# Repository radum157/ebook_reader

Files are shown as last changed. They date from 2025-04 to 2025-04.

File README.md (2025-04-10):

###### Copyright Radu Marin 2025
## README
# OpenBook

# Table of content

1. [Hardware details](#hardware-details)
2. [Design](#design)
3. [Diagram](#diagram)
4. [Bill of Materials](#bill-of-materials)

# Hardware details

OpenBook is an e-reader platform based on ESP32-C6 with E-Paper display technology. This document outlines the hardware architecture, component selection, and design considerations.

### Primary components:

**ESP32-C6 Microcontroller**
- ESP32-C6-WROOM-1-N8 module

**E-Paper Display**
- Waveshare 7.5” e-Paper V2
- Connected via 24-pin FPC header
- MBR0530 diodes in drive circuit for voltage management
- Dedicated power regulation

### Power Management

**Battery System**
- CELLEVIA BATTERIES LP584174 3.7V / 1800mAh LiPo battery
- MCP73831 LiPo charging controller
- MAX17048G+T10 fuel gauge
- JST connector

**Voltage Regulation**
- XC6220A331MR-G LDO for stable 3.3V
- DMG2305UX-7 MOSFETs for reverse polarity protection
- BD5229G-TR supervisor for clean resets

### Storage & Memory

**SD Card**
- Full-size SD slot with presence detection
- SPI mode communication

**External Flash**
- W25Q512JVEIQ NOR Flash
- SPI interface with ESD protection

**RTC**
- DS3231SN precision timekeeper
- Super-cap backup power
- I2C interface shared with sensors

### Sensors & IO

**Environmental Sensing**
- BME688 for temperature, humidity, pressure, air quality
- I2C bus connection

**UI**
- Boot, Change and Reset buttons
- Test pads integrated as exposed copper

### Communication interfaces:

 * I2C:
    - Used for communication with the BME688 sensor and DS3231SN RTC.
    - Send/Receive data to/from the sensor and RTC.
    - Also used for MAX17048G+T10 fuel gauge monitoring
    - QWIIC connector for expansion

 * SPI:
    - Used for communication with the E-Paper display and SD Card.
    - The ESP32-C6 uses SPI to send data to the display and read/write to the SD card.
    - Also used for the external W25Q512JVEIQ flash memory

 * GPIO:
    - Used for the reset/boot button and other custom functionalities.

**USB-C**
- USB4110-GF-A connector
- USBLC6-2SC6Y for ESD protection on data lines
- Charging and data transfer

**SPI Configuration**
- 10MHz clock rate
- Individual chip selects
- Shared data and clock lines

**I2C Setup**
- 400kHz standard mode
- 4.7kΩ pull-ups
- Shared among BME688, MAX17048G+T10, DS3231SN, and QWIIC port

**USB Interface**
- 5V, 500mA input

### Pins used:

| Pin | Function | Connected To | Why |
|-----|---|---|---|
| GPIO0 | BOOT | Boot/Reset Button | Flash mode access |
| GPIO1/2 | UART | USB-Serial | Debugging |
| GPIO3-4, 6-7 | SD Card | SD interface | Dedicated SD pins for reliability |
| GPIO5 | EPD_CS | E-Paper CS line | Display control |
| GPIO8 | FLASH_CS | External Flash | Flash memory selection |
| GPIO9-11 | SPI Bus | Shared SPI | Central bus for all SPI devices |
| GPIO12-13 | I2C Bus | Sensors & expansion | Shared I2C for all sensors |
| GPIO14-16 | EPD Control | E-Paper control signals | Timing control |
| GPIO17 | ADC | Battery voltage | Power monitoring |
| GPIO19-23 | EPD Data | E-Paper data lines | Display data transfer |

### Power consumption:
- Display refresh: ~125mA @ 3.3V
- Idle: ~25mA @ 3.3V
- Deep sleep: ~150μA @ 3.3V
- Duty cycle: 1-2 weeks typical use (1800mAh battery)

# Design

The final design of the PCB and 3D model attempt to minimize noise interference and maximize ease-of-use, while maintaining all of the core functionalities of OpenBook.

**Metoda de rezolvare / Probleme intampinate**

Schematic:

- Implemented following the electric design of the e-book reader
- Approved errors in relation to power pins

PCB 2D:

- Measured the dimensions and distances on the board and added the components accordingly (only on top layer)
- Approved errors in relation to board outline clearance (components in question needed to be closer to the enclosure)
- Added net classes to separate power lines from regular ones
- Created the power lines on top, with no vias, then the rest, all while attempting to optimize routing
- Added GND on top and bottom with no holes
- Via stitching close to ESP32

PCB 3D:

- Ensured soldermask layer is visible and at a small distance from the circuitry on the board
- Added accurate models for all components in use

Final 3D design:

- Added the pcb to the enclosure
- Modified the box shape for the SD, buttons etc. to fit
- Created a model for the Li-Po battery and 7.5” display
- Put everything together to ensure it fits

<br>

**The end result**

<br>

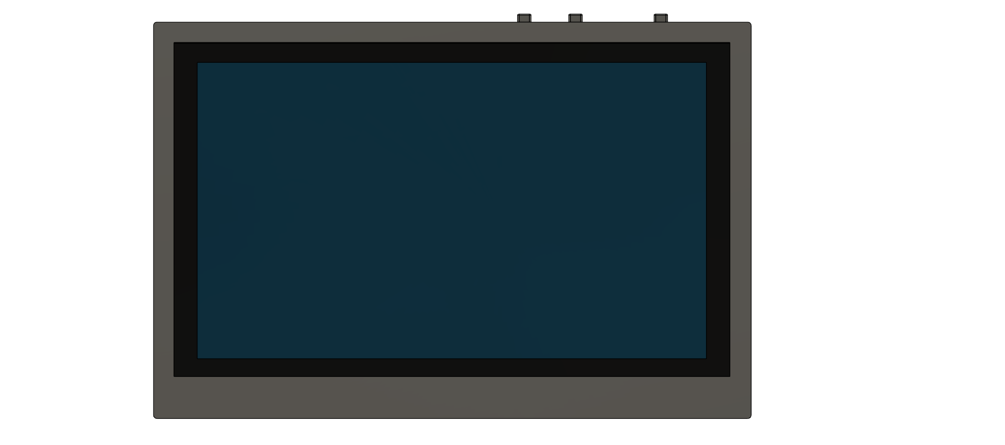
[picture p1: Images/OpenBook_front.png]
case1


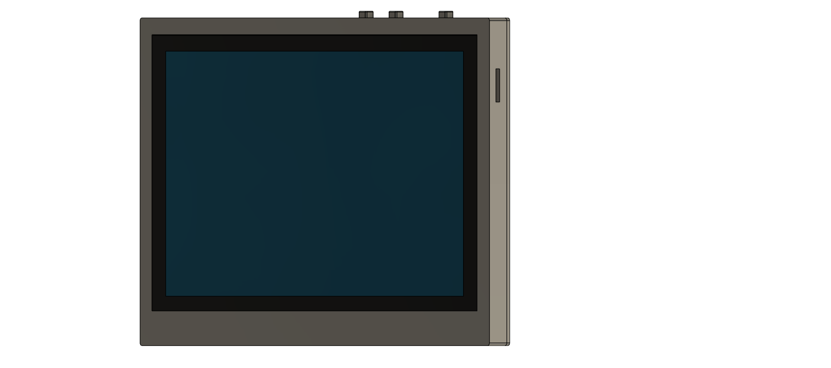
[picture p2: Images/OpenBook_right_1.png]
case2


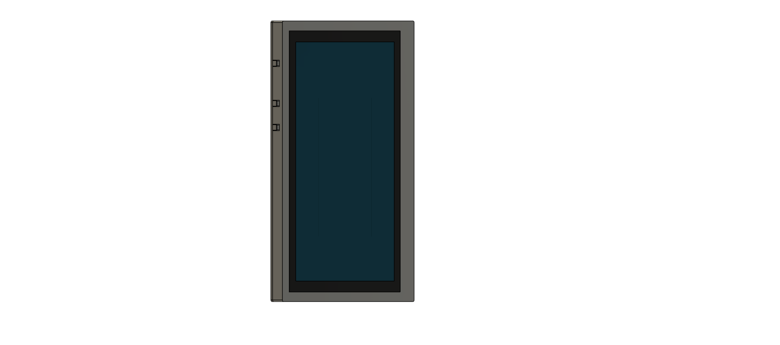
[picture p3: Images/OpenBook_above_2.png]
case3


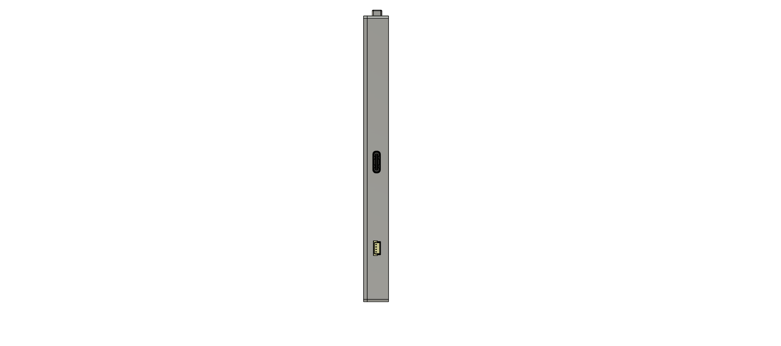
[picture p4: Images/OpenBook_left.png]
case4


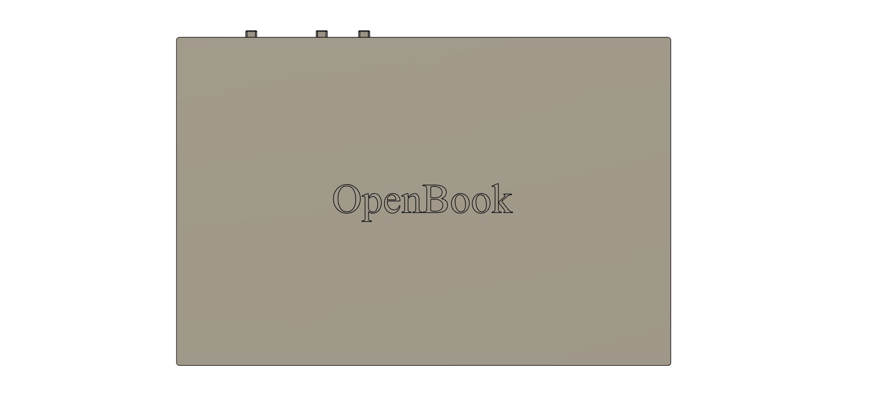
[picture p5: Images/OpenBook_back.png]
case5


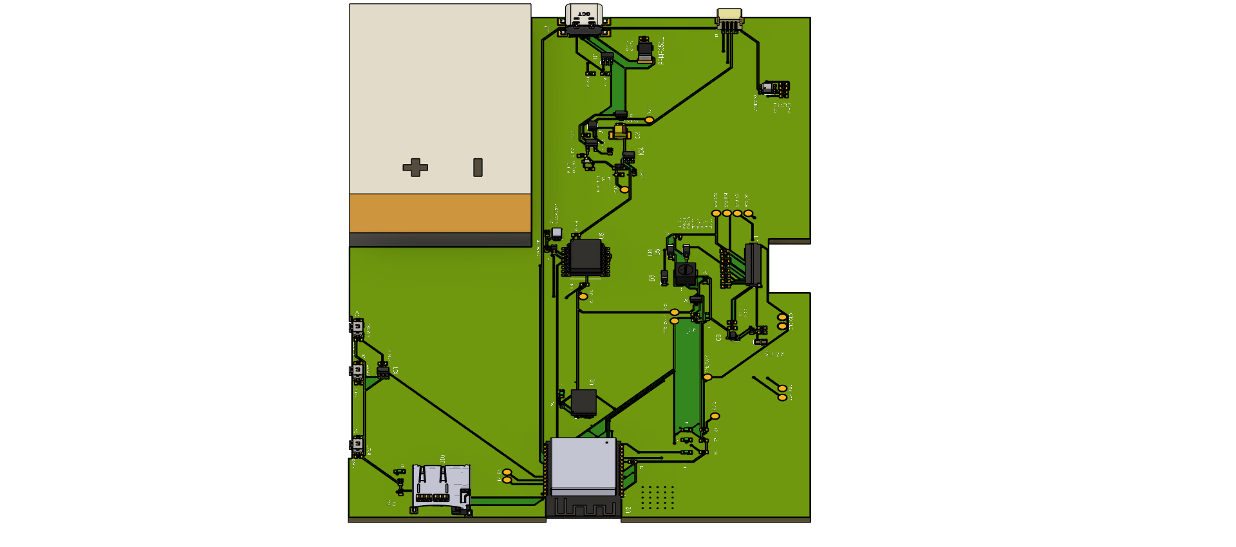
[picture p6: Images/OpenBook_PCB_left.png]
pcb1


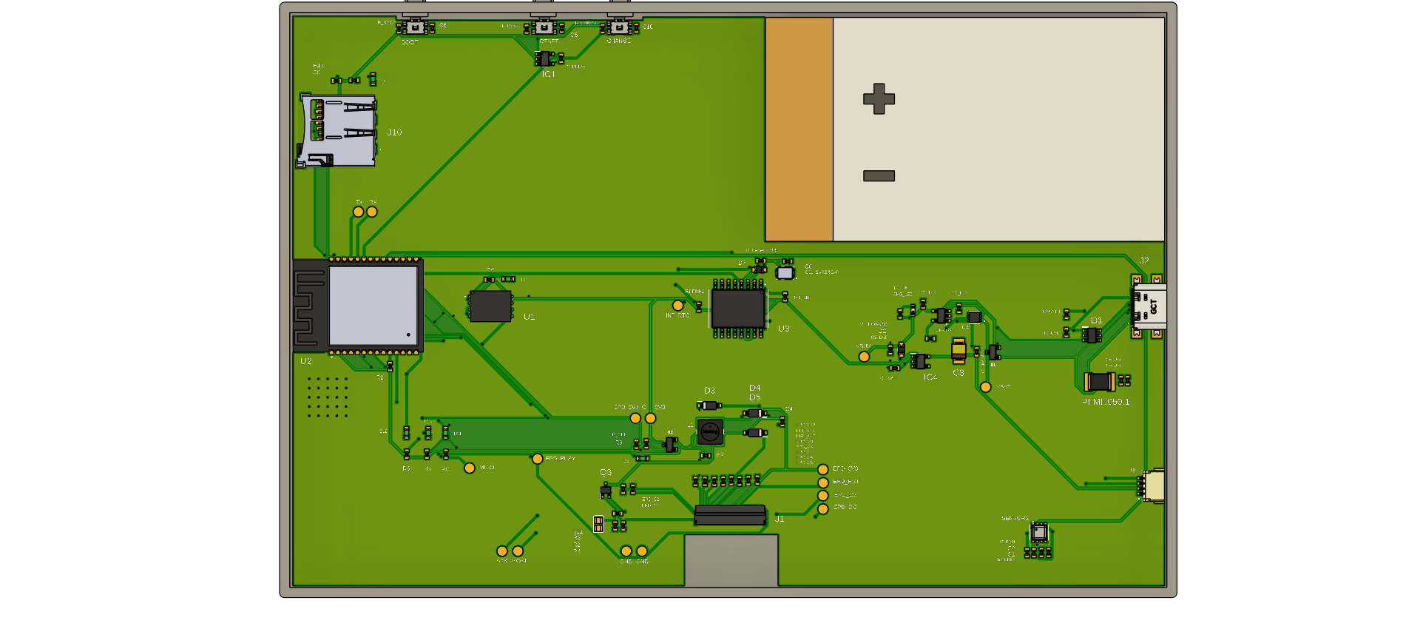
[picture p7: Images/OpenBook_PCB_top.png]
pcb2


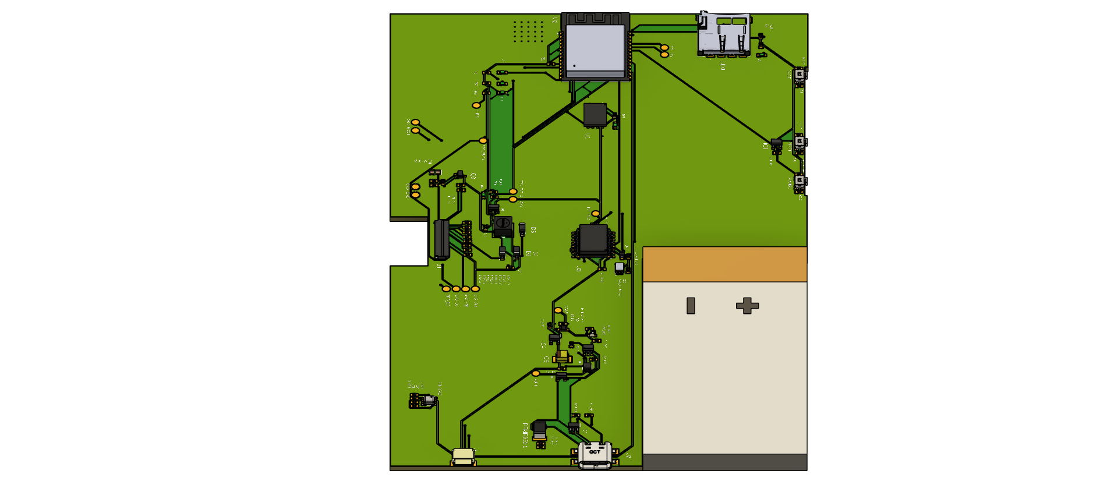
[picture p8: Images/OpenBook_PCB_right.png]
pcb3


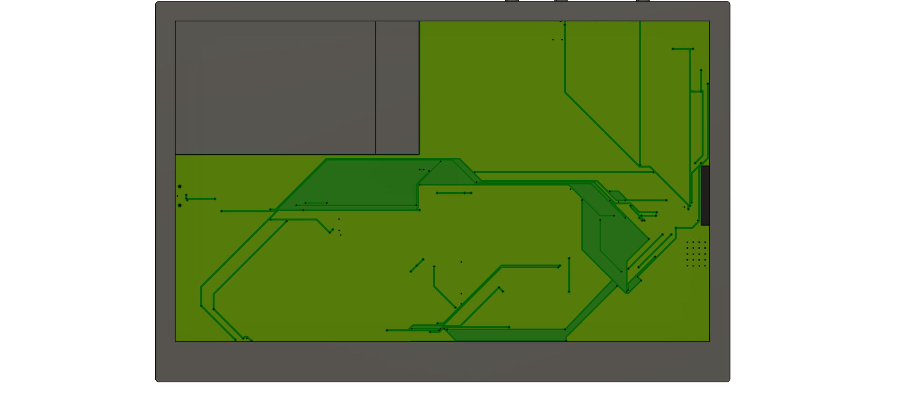
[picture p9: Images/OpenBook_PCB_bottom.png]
pcb4


# Diagram

diagram

# Bill of Materials

| Qty | Value | Device | Parts | CHECK_PRICES | DATASHEET |
|:---:|:---|:---|:---|:---|:---|
| 1 | 0.47 | ESP32_WROVER_EAGLE-LTSPICE_RR0402 | R3 | [YAGEO](https://componentsearchengine.com/part-view/R0402%201%25%20100%20K%20(RC0402FR-07100KL)/YAGEO) | [Datasheet](https://www.yageo.com/upload/media/product/products/datasheet/rchip/PYu-RC_Group_51_RoHS_L_12.pdf) |
| 1 | 100k | ESP32_WROVER_EAGLE-LTSPICE_RR0402 | R1_PWRUSB | [YAGEO](https://componentsearchengine.com/part-view/R0402%201%25%20100%20K%20(RC0402FR-07100KL)/YAGEO) | [Datasheet](https://www.yageo.com/upload/media/product/products/datasheet/rchip/PYu-RC_Group_51_RoHS_L_12.pdf) |
| 8 | 100nF | EAGLE-LTSPICE_CC0402 | C1, C2, C4_USB, C6, C8, C9, C10, C_DELAY | [YAGEO](https://componentsearchengine.com/part-view/CC0402MRX5R5BB106/YAGEO) | [Datasheet](https://ro.mouser.com/datasheet/2/447/upy_gphc_x5r_4v_to_50v-3461255.pdf) |
| 1 | 100uF TANT | RCL_CPOL-EUCT3528 | C3 | [Mouser](https://eu.mouser.com/ProductDetail/KYOCERA-AVX/TPSB106K025T1800?qs=qSfuJ%252Bfl%2Fd753zkuSz4nrg%3D%3D) | [Datasheet](https://eu.mouser.com/datasheet/2/40/TPS_AUTO-3165215.pdf) |
| 16 | 10k | ESP32_WROVER_EAGLE-LTSPICE_RR0402 | R1, R1-PINH, R1-PINH1, R2-PINH, R2-PINH1, R4, R5, R6, R7, R8, R9, R10, R_BOOT, R_CHANGE, R_CL1, R_RESET | [YAGEO](https://componentsearchengine.com/part-view/R0402%201%25%20100%20K%20(RC0402FR-07100KL)/YAGEO) | [Datasheet](https://www.yageo.com/upload/media/product/products/datasheet/rchip/PYu-RC_Group_51_RoHS_L_12.pdf) |
| 1 | 10uF | EAGLE-LTSPICE_CC0402 | C7 | [YAGEO](https://componentsearchengine.com/part-view/CC0402MRX5R5BB106/YAGEO) | [Datasheet](https://ro.mouser.com/datasheet/2/447/upy_gphc_x5r_4v_to_50v-3461255.pdf) |
| 1 | 112A-TAAR-R03_ATTEND | 112A-TAAR-R03_ATTEND | J10 | [Comet](https://store.comet.srl.ro/Catalogue/Product/43497/) | [Datasheet](https://www.attend.com.tw/en/product.php?act=view&id=253) |
| 1 | 15 | ESP32_WROVER_EAGLE-LTSPICE_RR0402 | R_CAPACITOR | [YAGEO](https://componentsearchengine.com/part-view/R0402%201%25%20100%20K%20(RC0402FR-07100KL)/YAGEO) | [Datasheet](https://www.yageo.com/upload/media/product/products/datasheet/rchip/PYu-RC_Group_51_RoHS_L_12.pdf) |
| 1 | 1m | SJ | SJ1 | - | - |
| 1 | 1uF | EAGLE-LTSPICE_CC0402 | C5 | [YAGEO](https://componentsearchengine.com/part-view/CC0402MRX5R5BB106/YAGEO) | [Datasheet](https://ro.mouser.com/datasheet/2/447/upy_gphc_x5r_4v_to_50v-3461255.pdf) |
| 10 | 1uF/50V | EAGLE-LTSPICE_CC0402 | EPD_C1, EPD_C2, EPD_C5, EPD_C6, EPD_C7, EPD_C8, EPD_C9, EPD_C10, EPD_C11, EPD_C12 | [YAGEO](https://componentsearchengine.com/part-view/CC0402MRX5R5BB106/YAGEO) | [Datasheet](https://ro.mouser.com/datasheet/2/447/upy_gphc_x5r_4v_to_50v-3461255.pdf) |
| 1 | 2.2 | ESP32_WROVER_EAGLE-LTSPICE_RR0402 | R2 | [YAGEO](https://componentsearchengine.com/part-view/R0402%201%25%20100%20K%20(RC0402FR-07100KL)/YAGEO) | [Datasheet](https://www.yageo.com/upload/media/product/products/datasheet/rchip/PYu-RC_Group_51_RoHS_L_12.pdf) |
| 1 | 200 | ESP32_WROVER_EAGLE-LTSPICE_RR0402 | R1_BAT | [YAGEO](https://componentsearchengine.com/part-view/R0402%201%25%20100%20K%20(RC0402FR-07100KL)/YAGEO) | [Datasheet](https://www.yageo.com/upload/media/product/products/datasheet/rchip/PYu-RC_Group_51_RoHS_L_12.pdf) |
| 2 | 20V/4.2A/52mO/1.4W | ESP32_WROVER_SPARKFUN-DISCRETESEMI_MOSFET_PCH-DMG2305UX-7 | Q1, Q2 | [Diodes Inc](https://componentsearchengine.com/part-view/DMG2305UX-7/Diodes%20Incorporated) | [Datasheet](https://www.diodes.com/assets/Datasheets/DMG2305UX.pdf) |
| 1 | 2k | ESP32_WROVER_EAGLE-LTSPICE_RR0402 | R2_BAT | [YAGEO](https://componentsearchengine.com/part-view/R0402%201%25%20100%20K%20(RC0402FR-07100KL)/YAGEO) | [Datasheet](https://www.yageo.com/upload/media/product/products/datasheet/rchip/PYu-RC_Group_51_RoHS_L_12.pdf) |
| 5 | 4.7uF | EAGLE-LTSPICE_CC0402 | C1_BAT, C1_BAT1, C1_BAT2, C2_BAT, C5_USB | [YAGEO](https://componentsearchengine.com/part-view/CC0402MRX5R5BB106/YAGEO) | [Datasheet](https://ro.mouser.com/datasheet/2/447/upy_gphc_x5r_4v_to_50v-3461255.pdf) |
| 1 | 4.7uF/25V | EAGLE-LTSPICE_CC0402 | C4 | [YAGEO](https://componentsearchengine.com/part-view/CC0402MRX5R5BB106/YAGEO) | [Datasheet](https://ro.mouser.com/datasheet/2/447/upy_gphc_x5r_4v_to_50v-3461255.pdf) |
| 2 | 5k1 | ESP32_WROVER_EAGLE-LTSPICE_RR0402 | R2-USB, R2-USB1 | [YAGEO](https://componentsearchengine.com/part-view/R0402%201%25%20100%20K%20(RC0402FR-07100KL)/YAGEO) | [Datasheet](https://www.yageo.com/upload/media/product/products/datasheet/rchip/PYu-RC_Group_51_RoHS_L_12.pdf) |
| 1 | 68uH | 744043680IND_4828-WE-TPC_WRE | L1 | [Mouser](https://eu.mouser.com/ProductDetail/Wurth-Elektronik/744043680?qs=PGXP4M47uW6VkZq%252BkzjrHA%3D%3D) | [Datasheet](https://www.we-online.com/components/products/datasheet/744043680.pdf) |
| 1 | BD5229G-TR | BD5229G-TR | IC1 | [ROHM](https://componentsearchengine.com/part-view/BD5229G-TR/ROHM%20Semiconductor) | [Datasheet](https://fscdn.rohm.com/en/products/databook/datasheet/ic/power/voltage_detector/bd52xxg-e.pdf) |
| 1 | BME688 | ESP32_WROVER_BME680_BME680 | SENSOR2 | [SnapEDA](https://www.snapeda.com/parts/BME680/Bosch/view-part/?welcome=home) | [Datasheet](https://www.snapeda.com/parts/BME680/Bosch%20Sensortec/datasheet/) |
| 3 | BUTTON_CUSYOMV1 | BUTTON_CUSYOMV1 | BOOT_BUTTON, CHANGE_BUTTON, RESET_BUTTON | [Panasonic](https://industry.panasonic.com/global/en/products/control/switch/light-touch/number/evqpuj02k) | [Datasheet](https://www.alldatasheet.com/datasheet-pdf/pdf/537835/PANASONIC/EVQPUJ02K.html) |
| 1 | CPH3225A | CPH3225A | C10_SUPERCAP | [SnapEDA](https://www.snapeda.com/parts/CPH3225A/Seiko+Instruments/view-part/?ref=eda) | [Datasheet](https://www.snapeda.com/parts/CPH3225A/Seiko%20Instruments/datasheet/) |
| 1 | DS3231SN# | DS3231SN# | U3 | [SnapEDA](https://www.snapeda.com/parts/DS3231SN%23/Analog+Devices/view-part/?ref=eda) | [Datasheet](https://www.snapeda.com/parts/DS3231SN%23/Analog%20Devices/datasheet/) |
| 1 | ESP32-C6-WROOM-1-N8 | ESP32-C6-WROOM-1-N8 | U2 | [SnapEDA](https://www.snapeda.com/parts/ESP32-C6-WROOM-1-N8/Espressif+Systems/view-part/?ref=eda) | [Datasheet](https://www.snapeda.com/parts/ESP32-C6-WROOM-1-N8/Espressif%20Systems/datasheet/) |
| 1 | ESP32C6_VARISTORCN1812 | ESP32C6_VARISTORCN1812 | PFMF.050.1 | [Digikey](https://www.digikey.com/en/products/detail/abracon-llc/AMCV-1812H-180-T/4245629) | [Datasheet](https://abracon.com/Magnetics/circuit_protection/AMCV-1812H.pdf) |
| 2 | ESP32_WROVER_AVX-SD0805S020S1R0 | ESP32_WROVER_AVX-SD0805S020S1R0 | D2, D7 | [Mouser](https://eu.mouser.com/ProductDetail/KYOCERA-AVX/SD0805S020S1R0?qs=jCA%252BPfw4LHbpkAoSnwrdjw%3D%3D) | [Datasheet](http://datasheets.avx.com/schottky.pdf) |
| 1 | ESP32_WROVER_SPARKFUN-IC-POWER_MCP73831 | ESP32_WROVER_SPARKFUN-IC-POWER_MCP73831 | MCP73831 | [Mouser](https://www.mouser.co.uk/ProductDetail/Microchip-Technology/MCP73831T-5ACI-OT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) | [Datasheet](https://www.mouser.co.uk/datasheet/2/268/MCP73831_Family_Data_Sheet_DS20001984H-3441711.pdf) |
| 1 | FH34SRJ-24S-0.5SH_99_ | FH34SRJ-24S-0.5SH_99_ | J1 | [Hirose](https://componentsearchengine.com/part-view/FH34SRJ-24S-0.5SH(99)/Hirose) | [Datasheet](https://www.hirose.com/en/product/document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) |
| 1 | MAX17048G+T10 | MAX17048G+T10 | U4 | [SnapEDA](https://www.snapeda.com/parts/MAX17048G+T10/Analog+Devices/view-part/?ref=eda) | [Datasheet](https://www.snapeda.com/parts/MAX17048G+T10/Analog%20Devices/datasheet/) |
| 3 | MBR0530 | MBR0530 | D3, D4, D5 | [SnapEDA](https://www.snapeda.com/parts/MBR0530/Onsemi/view-part/?ref=eda) | [Datasheet](https://www.snapeda.com/parts/MBR0530/ON%20Semiconductor/datasheet/) |
| 6 | PGB1010603MR | PGB1010603MR | D6, D8, D9, D10, D11, D12 | [SnapEDA](https://www.snapeda.com/parts/PGB1010603MR/Littelfuse/view-part/?ref=eda) | [Datasheet](https://www.snapeda.com/parts/PGB1010603MR/Littelfuse%20Inc./datasheet/) |
| 1 | QWIIC_RIGHT_ANGLE | QWIIC_CONNECTORJS-1MM | J3 | [SnapEDA](https://www.snapeda.com/parts/PRT-14417/SparkFun%20Electronics/view-part/?ref=search&t=qwiic) | [Datasheet](https://www.snapeda.com/parts/PRT-14417/SparkFun%20Electronics/datasheet/) |
| 1 | SAMACSYS_PARTS_USB4110-GF-A | SAMACSYS_PARTS_USB4110-GF-A | J2 | [GCT](https://componentsearchengine.com/part-view/USB4110-GF-A/GCT%20(GLOBAL%20CONNECTOR%20TECHNOLOGY)) | [Datasheet](https://ro.mouser.com/datasheet/2/837/GCT_USB4110_Product_Drawing___20k_cycles-3455479.pdf) |
| 1 | SI1308EDL-T1-GE3 | SI1308EDL-T1-GE3 | Q3 | [SnapEDA](https://www.snapeda.com/parts/SI1308EDL-T1-GE3/Vishay+Siliconix/view-part/?ref=eda) | [Datasheet](https://www.snapeda.com/parts/SI1308EDL-T1-GE3/Vishay%20Siliconix/datasheet/) |
| 1 | SMD-LED0603 | ADAFRUIT_LEDCHIP-LED0603 | CHG_LED | [SnapEDA](https://www.snapeda.com/parts/KP-1608SURCK/Kingbright/view-part/?ref=search&t=LED%200603) | [Datasheet](https://www.snapeda.com/parts/KP-1608SURCK/Kingbright/datasheet/) |
| 17 | TPTP20R | TPTP20R | TP1, TP2, TP3, TP4, TP5, TP6, TP7, TP8, TP9, TP10, TP11, TP12, TP13, TP14, TP15, TP16, TP17 | - | - |
| 1 | USBLC6-2SC6Y | USBLC6-2SC6Y | D1 | [SnapEDA](https://www.snapeda.com/parts/USBLC6-2SC6Y/STMicroelectronics/view-part/?ref=eda) | [Datasheet](https://www.snapeda.com/parts/USBLC6-2SC6Y/STMicroelectronics/datasheet/) |
| 1 | W25Q512JVEIQ | W25Q512JVEIQ | U1 | [SnapEDA](https://www.snapeda.com/parts/W25Q512JVEIQ/Winbond+Electronics/view-part/?ref=eda) | [Datasheet](https://www.snapeda.com/parts/W25Q512JVEIQ/Winbond%20Electronics/datasheet/) |
| 1 | XC6220A331MR-G | XC6220A331MR-G | IC4 | [Torex](https://componentsearchengine.com/part-view/XC6220A331MR-G/Torex) | [Datasheet](https://eu.mouser.com/datasheet/2/760/xc6220-3371556.pdf) |

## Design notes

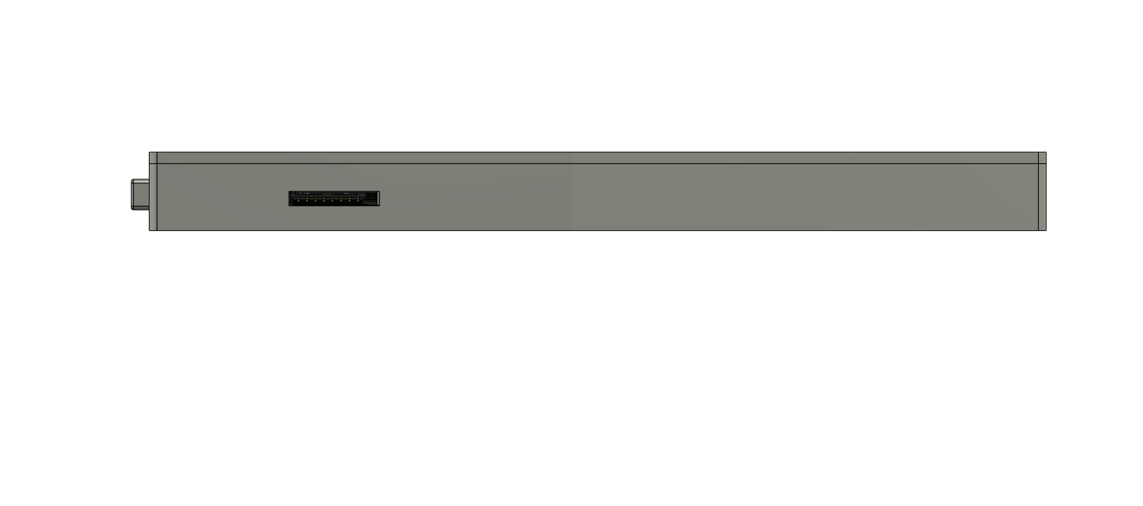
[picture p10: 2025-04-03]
Images/OpenBook_right_2.png

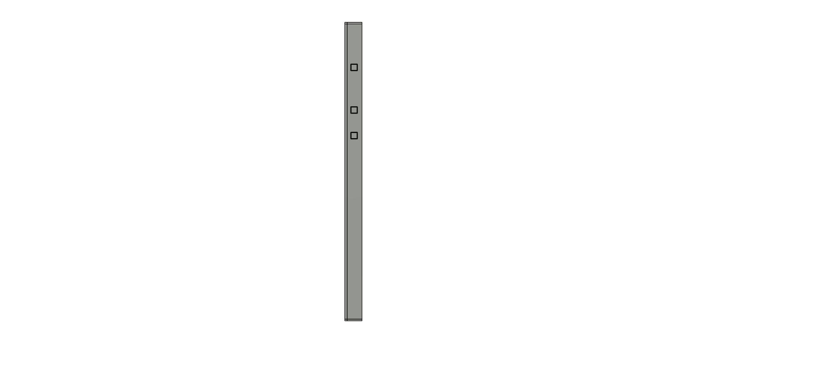
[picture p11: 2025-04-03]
Images/OpenBook_above_1.png

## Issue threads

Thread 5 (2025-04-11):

Gaps in ground plane

patriciacraciun, 2025-04-11:
The ground plane has unnecessary gaps, it should be continuous.

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

radum157, 2025-04-11:
This seems to be an issue with how fusion saves the board. This is how it actually looks for referrence.

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

Closed 2025-04-11.

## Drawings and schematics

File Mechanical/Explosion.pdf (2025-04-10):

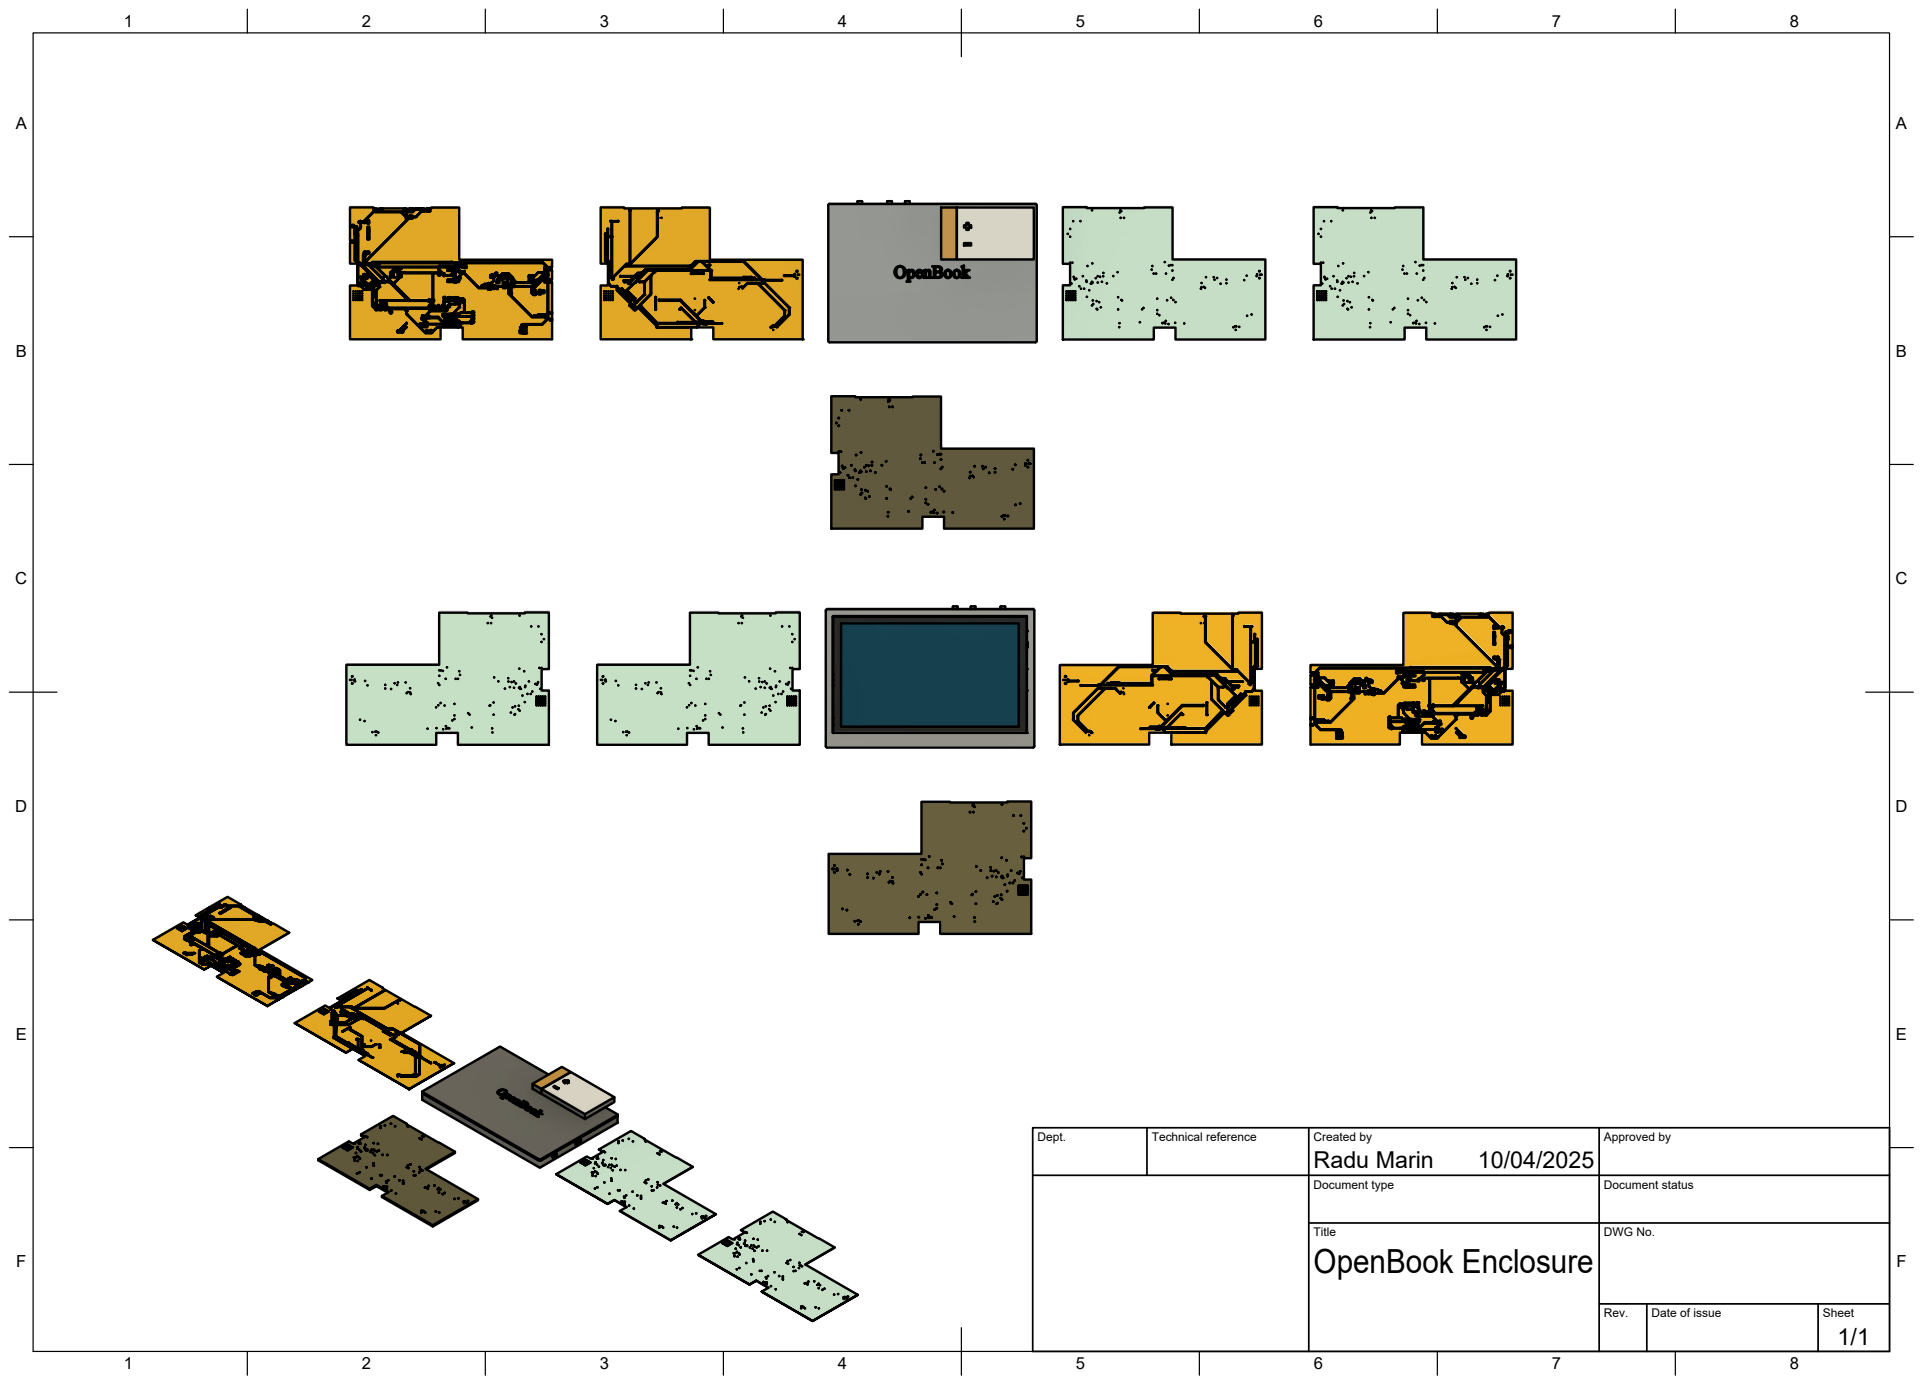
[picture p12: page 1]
Dept.; Technical reference; Created by; Approved by; Document type; Document status; Title; DWG No.; Rev.; Date of issue; Sheet; OpenBook Enclosure; Radu Marin

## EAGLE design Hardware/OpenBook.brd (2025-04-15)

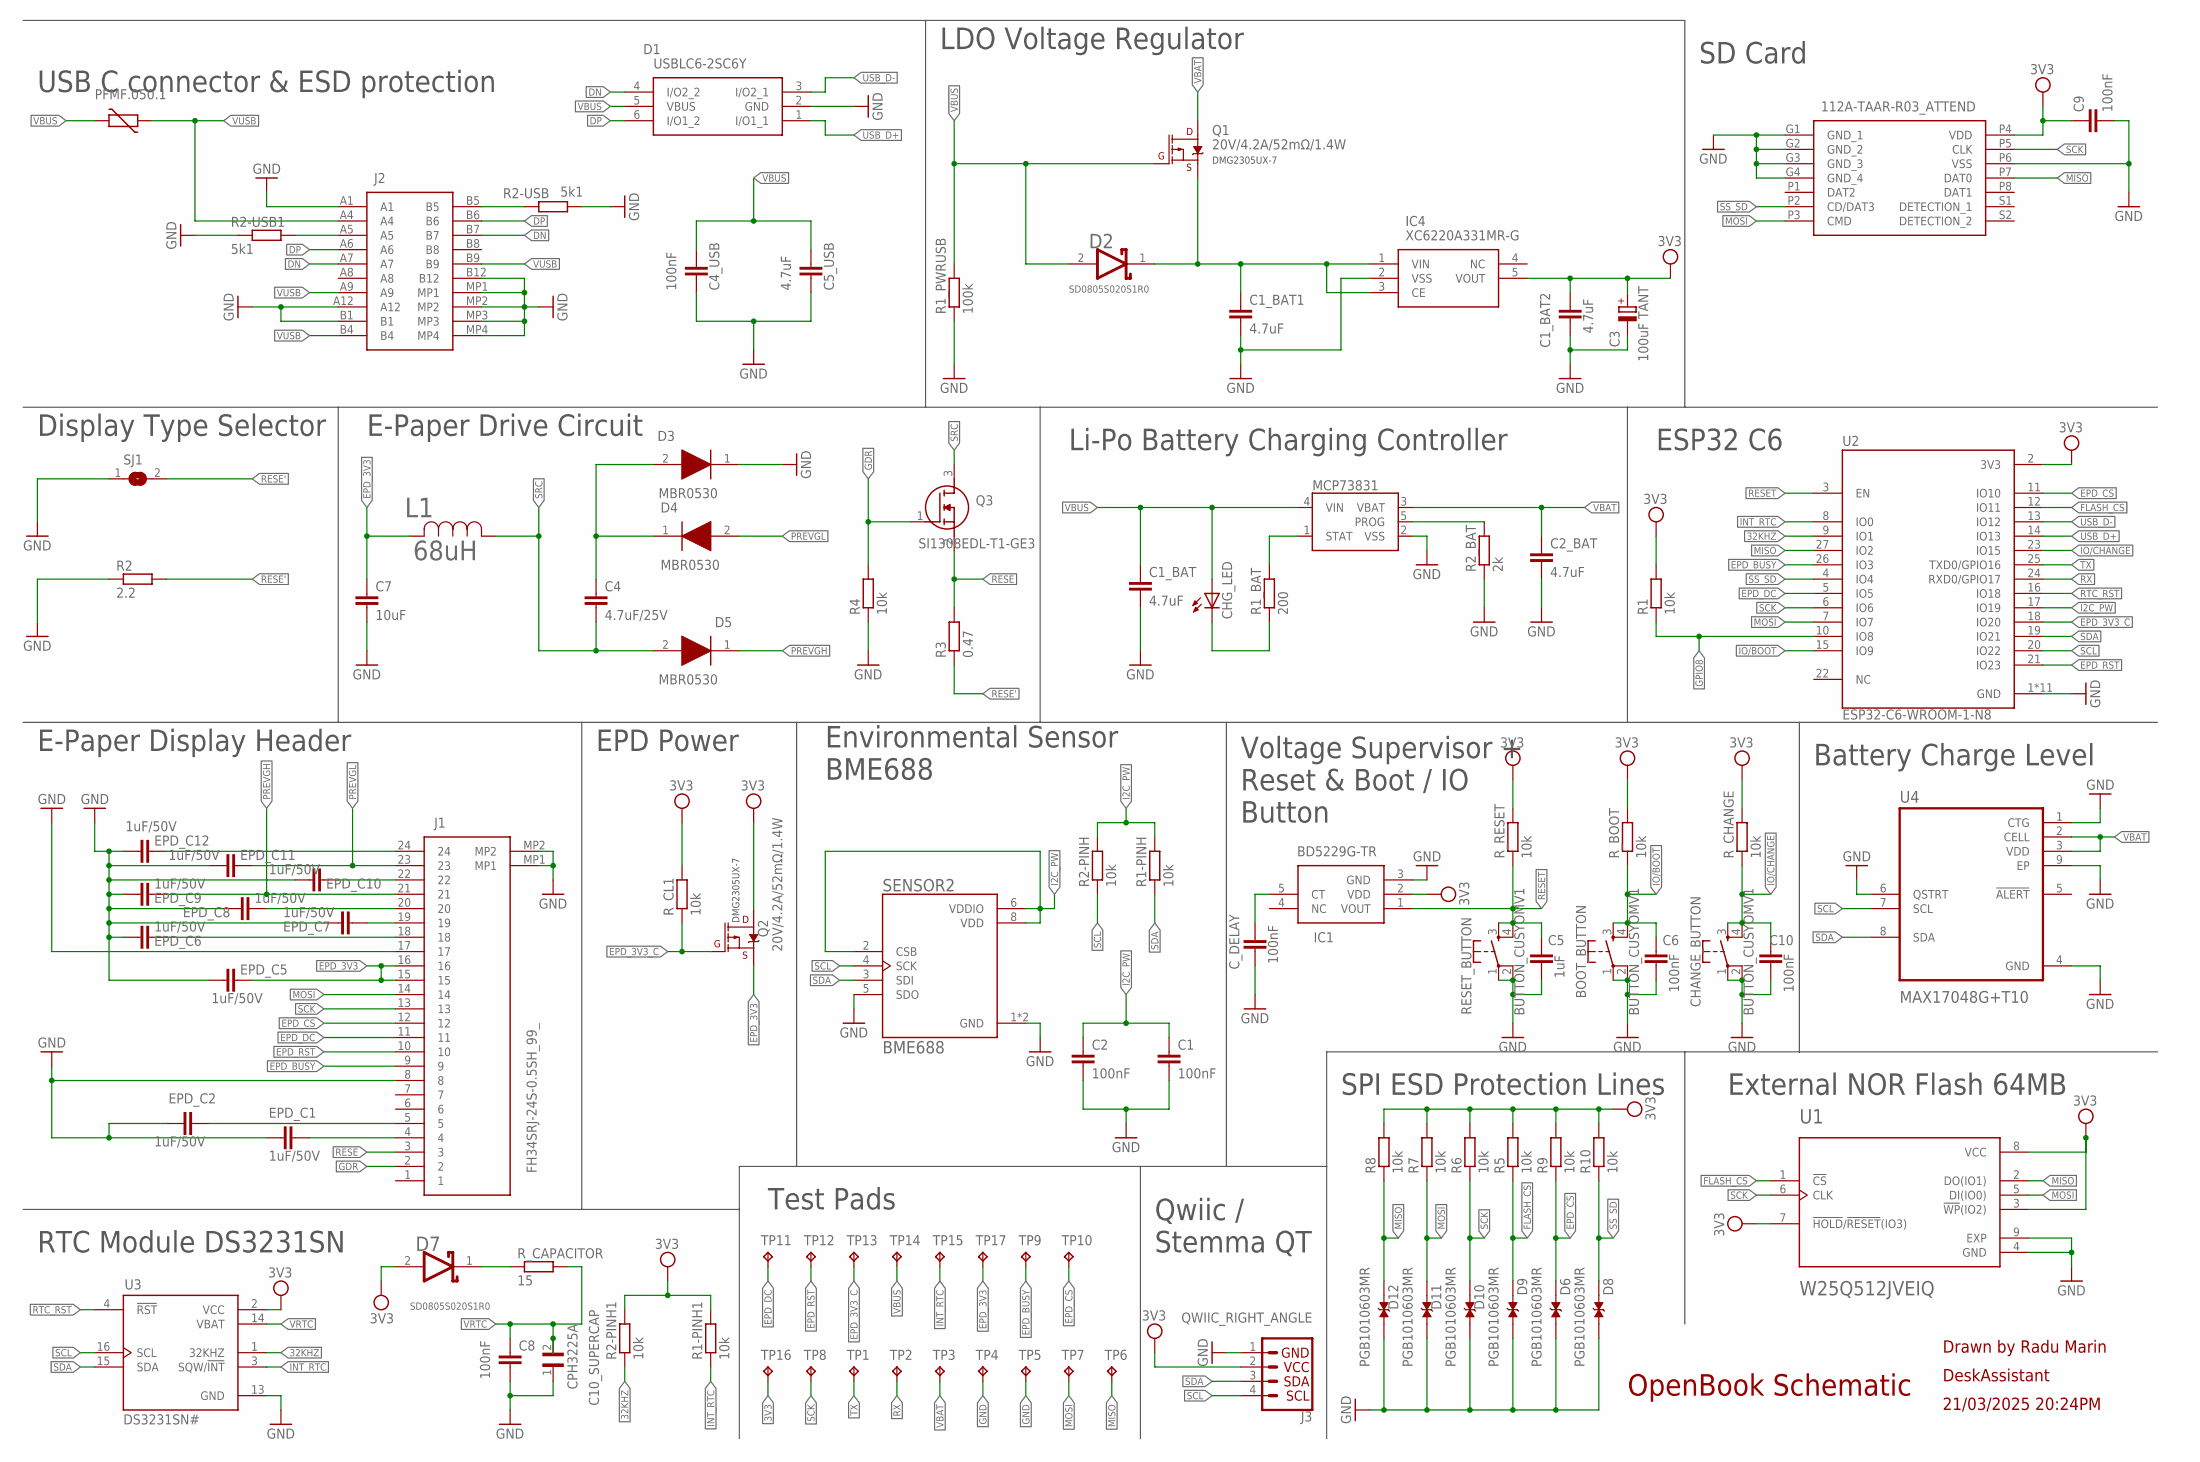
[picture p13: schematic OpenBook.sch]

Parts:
BOOT_BUTTON: BUTTON_CUSYOMV1; MYBUTTON
C1, C2, C4_USB, C6, C8, C9, C10: 100nF; EAGLE-LTSPICE_C0402
C1_BAT, C1_BAT1, C1_BAT2, C2_BAT, C5_USB: 4.7uF; EAGLE-LTSPICE_C0402
C3: 100uF TANT; RCL_CT3528
C4: 4.7uF/25V; EAGLE-LTSPICE_C0402
C5: 1uF; EAGLE-LTSPICE_C0402
C7: 10uF; EAGLE-LTSPICE_C0402
C10_SUPERCAP: CPH3225A; CAPCP3225X100N
CHANGE_BUTTON: BUTTON_CUSYOMV1; MYBUTTON
CHG_LED: SMD-LED0603; ADAFRUIT_CHIP-LED0603
C_DELAY: 100nF; EAGLE-LTSPICE_C0402
D1: USBLC6-2SC6Y; SOT95P280X145-6N
D2, D7: ESP32_WROVER_AVX---SD0805S020S1R0_AVX_SD0805S020S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; ESP32_WROVER_AVX---SD0805S020S1R0_AVX_SD0805S020S1R0_0
D3, D4, D5: MBR0530; SOD3716X135N
D6, D8, D9, D10, D11, D12: PGB1010603MR; DIOC1608X36N
EPD_C1, EPD_C2, EPD_C5, EPD_C6, EPD_C7, EPD_C8, EPD_C9, EPD_C10, EPD_C11, EPD_C12: 1uF/50V; EAGLE-LTSPICE_C0402
IC1: BD5229G-TR; SOT95P280X125-5N
IC4: XC6220A331MR-G; SOT95P280X120-5N
J1: FH34SRJ-24S-0.5SH_99_; FH34SRJ24S05SH99
J2: SAMACSYS_PARTS_USB4110-GF-A; SAMACSYS_PARTS_USB4110GFA
J3: QWIIC_RIGHT_ANGLE; JST04_1MM_RA
J10: 112A-TAAR-R03_ATTEND; 112ATAARR03ATTEND
L1: 68uH; IND_4828-WE-TPC_WRE
MCP73831: ESP32_WROVER_SPARKFUN-IC-POWER_MCP73831; ESP32_WROVER_SPARKFUN-IC-POWER_SOT23-5
PFMF.050.1: ESP32C6_VARISTORCN1812; ESP32C6_VARISTOR_CT/CN1812
Q1, Q2: 20V/4.2A/52mΩ/1.4W; ESP32_WROVER_SPARKFUN-DISCRETESEMI_SOT23-3
Q3: SI1308EDL-T1-GE3; SOT65P210X110-3N
R1, R1-PINH, R1-PINH1, R2-PINH, R2-PINH1, R4, R5, R6, R7, R8, R9, R10: 10k; ESP32_WROVER_EAGLE-LTSPICE_R0402
R1_BAT: 200; ESP32_WROVER_EAGLE-LTSPICE_R0402
R1_PWRUSB: 100k; ESP32_WROVER_EAGLE-LTSPICE_R0402
R2: 2.2; ESP32_WROVER_EAGLE-LTSPICE_R0402
R2-USB, R2-USB1: 5k1; ESP32_WROVER_EAGLE-LTSPICE_R0402
R2_BAT: 2k; ESP32_WROVER_EAGLE-LTSPICE_R0402
R3: 0.47; ESP32_WROVER_EAGLE-LTSPICE_R0402
RESET_BUTTON: BUTTON_CUSYOMV1; MYBUTTON
R_BOOT: 10k; ESP32_WROVER_EAGLE-LTSPICE_R0402
R_CAPACITOR: 15; ESP32_WROVER_EAGLE-LTSPICE_R0402
R_CHANGE: 10k; ESP32_WROVER_EAGLE-LTSPICE_R0402
R_CL1: 10k; ESP32_WROVER_EAGLE-LTSPICE_R0402
R_RESET: 10k; ESP32_WROVER_EAGLE-LTSPICE_R0402
SENSOR2: BME688; ESP32_WROVER_BME680_PSON80P300X300X100-8N
SJ1: 1m; SJ
TP1, TP2, TP3, TP4, TP5, TP6, TP7, TP8, TP9, TP10, TP11, TP12, TP13, TP14, TP15, TP16, TP17: TPTP20R; TP20R
U1: W25Q512JVEIQ; SON127P600X800X80-9N
U2: ESP32-C6-WROOM-1-N8; XCVR_ESP32-C6-WROOM-1-N8
U3: DS3231SN#; SOIC127P1032X265-16N
U4: MAX17048G+T10; SON50P200X200X80-9N

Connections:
3V3: C1_BAT2.1, C3.+, C9.1, D7.2 (ANODE), IC1.2 (VDD), IC4.5 (VOUT), J3.2, J10.P4 (VDD), Q2.3 (D), R1.2, R1-PINH1.2, R2-PINH1.2, R5.2, R6.2, R7.2, R8.2, R9.2, R10.2, R_BOOT.2, R_CHANGE.2, R_CL1.2, R_RESET.2, TP16.TP, U1.3 (!WP!(IO2)), U1.7 (!HOLD!/!RESET!(IO3)), U1.8 (VCC), U2.2 (3V3), U3.2 (VCC)
32KHZ: R2-PINH1.1, U2.9 (IO1), U3.1 (32KHZ)
DN: D1.4 (I/O2_2), J2.A7, J2.B7
DP: D1.6 (I/O1_2), J2.A6, J2.B6
EPD_3V3: C7.1, EPD_C5.1, J1.15, J1.16, L1.2, Q2.2 (S), TP17.TP
EPD_3V3_C: Q2.1 (G), R_CL1.1, TP13.TP, U2.18 (IO20)
EPD_BUSY: J1.9, TP9.TP, U2.26 (IO3)
EPD_CS: D6.2, J1.12, R9.1, TP10.TP, U2.11 (IO10)
EPD_DC: J1.11, TP11.TP, U2.5 (IO5)
EPD_RST: J1.10, TP12.TP, U2.21 (IO23)
FLASH_CS: D9.2, R5.1, U1.1 (!CS), U2.12 (IO11)
GDR: J1.2, Q3.1 (G), R4.2
GND: BOOT_BUTTON.1, BOOT_BUTTON.2, C1.2, C1_BAT.2, C1_BAT1.2, C1_BAT2.2, C2.2, C2_BAT.2, C3.-, C4_USB.2, C5.2, C5_USB.2, C6.2, C7.2, C8.2, C9.2, C10.2, C10_SUPERCAP.1, CHANGE_BUTTON.1, CHANGE_BUTTON.2, C_DELAY.2, D1.2 (GND), D3.1 (K), D6.1, D8.1, D9.1, D10.1, D11.1, D12.1, EPD_C1.2, EPD_C2.2, EPD_C5.2, EPD_C6.2, EPD_C7.2, EPD_C8.2, EPD_C9.2, EPD_C10.2, EPD_C11.2, EPD_C12.2, IC1.3 (GND), IC4.2 (VSS), J1.8, J1.17, J1.MP1, J1.MP2, J2.A1, J2.A12, J2.B1, J2.B12, J2.MP1, J2.MP2, J2.MP3, J2.MP4, J3.1, J10.G1 (GND_1), J10.G2 (GND_2), J10.G3 (GND_3), J10.G4 (GND_4), J10.P6 (VSS), MCP73831.2 (VSS), R1_PWRUSB.1, R2.1, R2-USB.2, R2-USB1.1, R2_BAT.1, R4.1, RESET_BUTTON.1, RESET_BUTTON.2, SENSOR2.1 (GND), SENSOR2.5 (SDO), SENSOR2.7 (GND), SJ1.1, TP4.TP, TP5.TP, U1.4 (GND), U1.9 (EXP), U2.1 (GND), U2.28 (GND), U2.29_1 (GND), U2.29_2 (GND), U2.29_3 (GND), U2.29_4 (GND), U2.29_5 (GND), U2.29_6 (GND), U2.29_7 (GND), U2.29_8 (GND), U2.29_9 (GND), U3.13 (GND), U4.1 (CTG), U4.4 (GND), U4.6 (QSTRT), U4.9 (EP)
GPIO8: R1.1, U2.10 (IO8)
I2C_PW: C1.1, C2.1, R1-PINH.2, R2-PINH.2, SENSOR2.2 (CSB), SENSOR2.6 (VDDIO), SENSOR2.8 (VDD), U2.17 (IO19)
INT_RTC: R1-PINH1.1, TP15.TP, U2.8 (IO0), U3.3 (SQW/!INT)
IO/BOOT: BOOT_BUTTON.3, BOOT_BUTTON.4, C6.1, R_BOOT.1, U2.15 (IO9)
IO/CHANGE: C10.1, CHANGE_BUTTON.3, CHANGE_BUTTON.4, R_CHANGE.1, U2.23 (IO15)
MISO: D12.2, J10.P7 (DAT0), R8.1, TP6.TP, U1.2 (DO(IO1)), U2.27 (IO2)
MOSI: D11.2, J1.14, J10.P3 (CMD), R7.1, TP7.TP, U1.5 (DI(IO0)), U2.7 (IO7)
unnamed: J2.B5, R2-USB.1
unnamed: J2.A5, R2-USB1.2
unnamed: CHG_LED.C, R1_BAT.1
unnamed: C1_BAT1.1, D2.1 (CATHODE), IC4.1 (VIN), IC4.3 (CE), Q1.2 (S)
unnamed: C4.1, D3.2 (A), D4.1 (K)
unnamed: MCP73831.1 (STAT), R1_BAT.2
unnamed: MCP73831.5 (PROG), R2_BAT.2
unnamed: EPD_C12.1, J1.24
unnamed: EPD_C10.1, J1.22
unnamed: EPD_C8.1, J1.20
unnamed: EPD_C7.1, J1.19
unnamed: EPD_C6.1, J1.18
unnamed: EPD_C2.1, J1.5
unnamed: EPD_C1.1, J1.4
unnamed: C_DELAY.1, IC1.5 (CT)
unnamed: D7.1 (CATHODE), R_CAPACITOR.1
PREVGH: D5.1 (K), EPD_C9.1, J1.21
PREVGL: D4.2 (A), EPD_C11.1, J1.23
RESE: J1.3, Q3.2 (S), R3.2
RESE': R2.2, R3.1, SJ1.2
RESET: C5.1, IC1.1 (VOUT), RESET_BUTTON.3, RESET_BUTTON.4, R_RESET.1, U2.3 (EN)
RTC_RST: U2.16 (IO18), U3.4 (!RST)
RX: TP2.TP, U2.24 (RXD0/GPIO17)
SCK: D10.2, J1.13, J10.P5 (CLK), R6.1, TP8.TP, U1.6 (CLK), U2.6 (IO6)
SCL: J3.4, R2-PINH.1, SENSOR2.4 (SCK), U2.20 (IO22), U3.16 (SCL), U4.7 (SCL)
SDA: J3.3, R1-PINH.1, SENSOR2.3 (SDI), U2.19 (IO21), U3.15 (SDA), U4.8 (SDA)
SRC: C4.2, D5.2 (A), L1.1, Q3.3 (D)
SS_SD: D8.2, J10.P2 (CD/DAT3), R10.1, U2.4 (IO4)
TX: TP1.TP, U2.25 (TXD0/GPIO16)
USB_D+: D1.1 (I/O1_1), U2.14 (IO13)
USB_D-: D1.3 (I/O2_1), U2.13 (IO12)
VBAT: C2_BAT.1, MCP73831.3 (VBAT), Q1.3 (D), TP3.TP, U4.2 (CELL), U4.3 (VDD)
VBUS: C1_BAT.1, C4_USB.1, C5_USB.1, CHG_LED.A, D1.5 (VBUS), D2.2 (ANODE), MCP73831.4 (VIN), PFMF.050.1.2, Q1.1 (G), R1_PWRUSB.2, TP14.TP
VRTC: C8.1, C10_SUPERCAP.2, R_CAPACITOR.2, U3.14 (VBAT)
VUSB: J2.A4, J2.A9, J2.B4, J2.B9, PFMF.050.1.1

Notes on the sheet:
DMG2305UX-7
SD0805S020S1R0
USB C connector & ESD protection
LDO Voltage Regulator
SD Card
ESP32 C6
Display Type Selector
E-Paper Drive Circuit
Li-Po Battery Charging Controller
E-Paper Display Header
EPD Power
Voltage Supervisor + Reset & Boot / IO Button
Battery Charge Level
RTC Module DS3231SN
Test Pads
Qwiic / Stemma QT
SPI ESD Protection Lines
External NOR Flash 64MB
Environmental Sensor BME688
OpenBook Schematic
Drawn by Radu Marin
DeskAssistant
21/03/2025 20:24PM

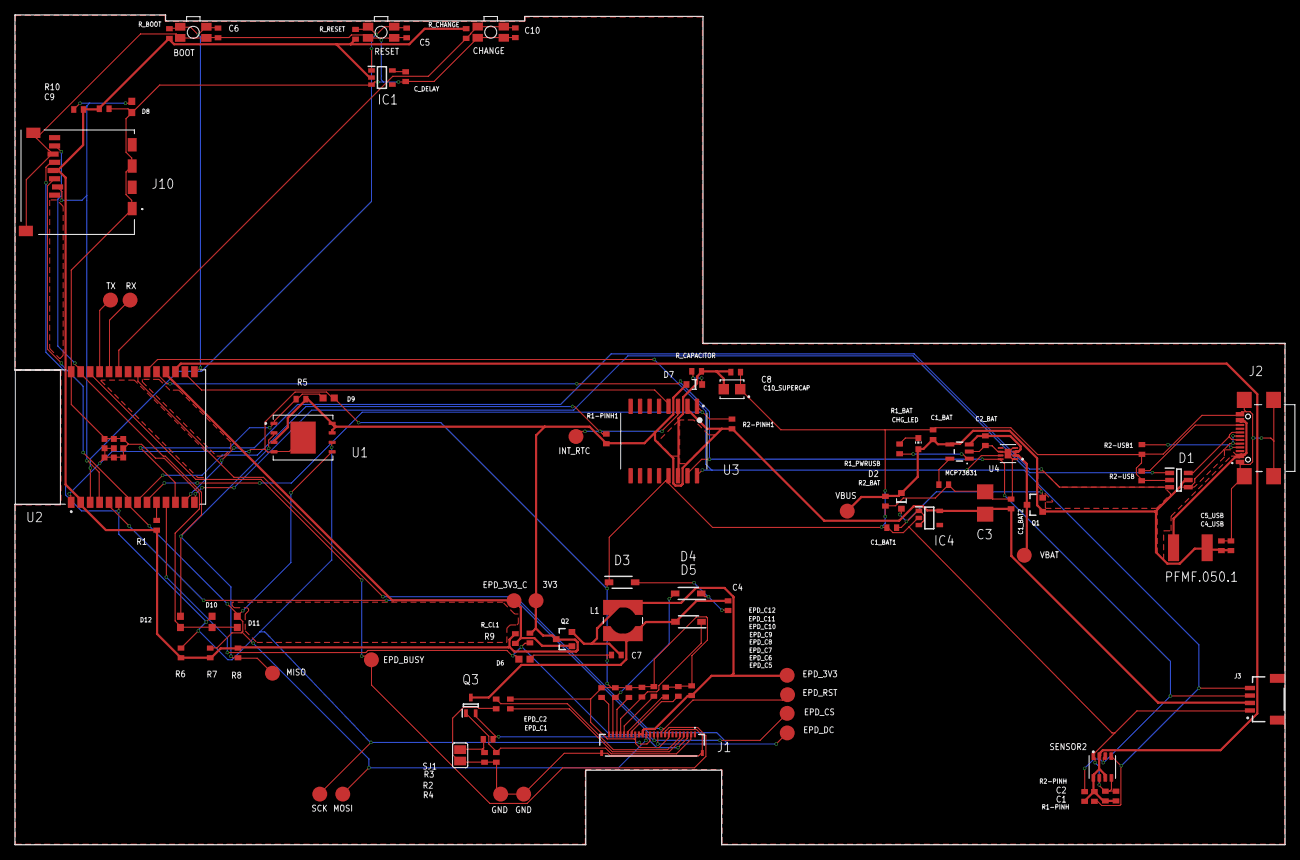
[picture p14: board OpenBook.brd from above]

Board: 2 copper layers, 170.2 x 111.2 mm, 103 parts (0 on the bottom side), 55 nets.

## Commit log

2025-03-21 Added schematic
    [OpenBook.sch]
2025-03-21 Update sch
    [OpenBook.sch]
2025-03-31 Add PCB
    [OpenBook.brd]
2025-04-03 Add 3D model
    [OpenBook.brd, OpenBook.sch]
2025-04-03 Add manufacturing
    [bom.csv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]
2025-04-03 Update files. Add README data.
    [bom.csv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]
2025-04-04 v1.1.0 fix(bom): add datasheets
2025-04-06 fix(bom): fill in missing data
2025-04-10 fix(issue#3): reduced vias
    [OpenBook.brd]
2025-04-10 patch: fix errors after fixes
    [OpenBook.brd, OpenBook.sch]
2025-04-11 fix(pcb): board height
    [OpenBook.brd]
2025-04-14 fix(height): adjust for PCB thickness change
2025-04-15 feat(PCB): add dimensions
    [OpenBook.brd]

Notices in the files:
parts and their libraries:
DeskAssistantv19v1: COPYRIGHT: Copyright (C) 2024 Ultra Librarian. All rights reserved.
